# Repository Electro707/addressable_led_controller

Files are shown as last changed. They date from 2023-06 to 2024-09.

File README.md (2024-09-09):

# Addressable LED Strip Controller
#### Rev 4

This is the repository for my LED strip controller. This LED controller is capable of controlling any addressable LED strip (1 or two data wires).

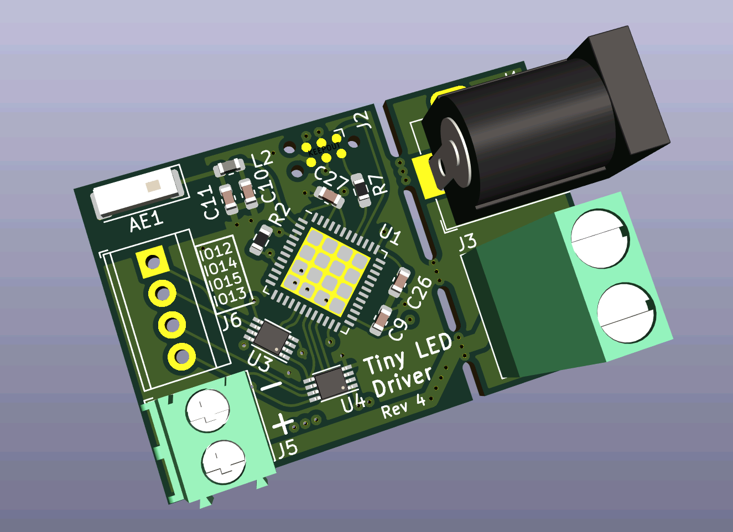
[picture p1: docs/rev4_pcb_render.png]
PCB render of Rev4


`Image of real PCB Rev4 coming soon!`

## Firmware

This controller uses the [WLED firmware](https://github.com/Aircoookie/WLED). Instructions to upload the firmware unto the board can be found on their webpage.

Thru J2, you can connect an ESP32 programmer such as the ESP-Prog. You can also make your own "automatic downloader" (i.e not requiring to reset the device and selecting boot mode when uploading) circuit. Details of which can be found on Espressif's ESP-Prog docs on [Automatic Downloading Function](https://espressif-docs.readthedocs-hosted.com/projects/espressif-esp-iot-solution/en/latest/hw-reference/ESP-Prog_guide.html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).

## PI Matching Network Values

#### Rev 2

The PI Matching network values have been calculated by measuring the impedance of the antenna mounted on a bare board. As image of the setup is shown below:

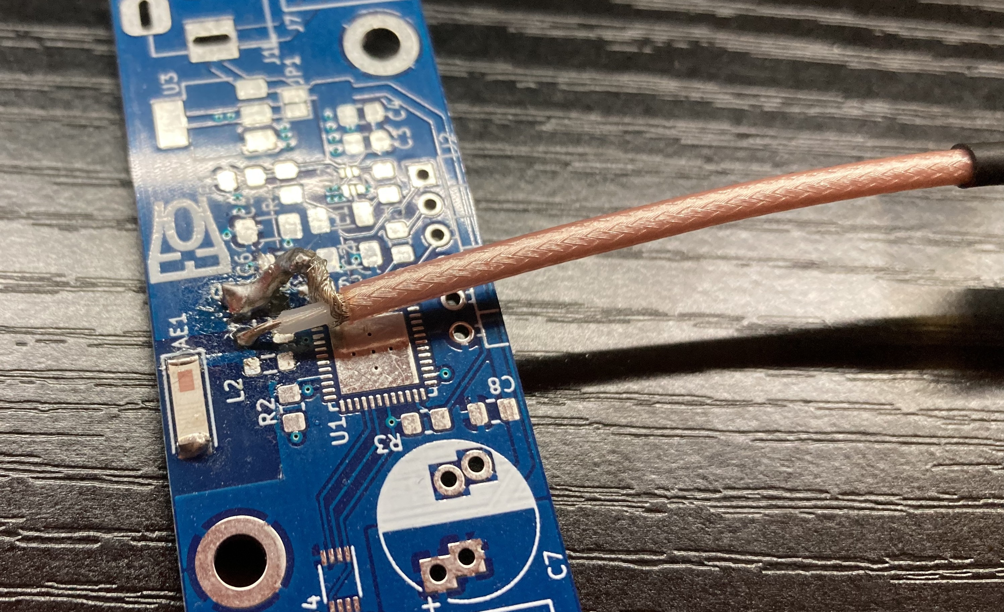
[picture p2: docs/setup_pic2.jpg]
Image of PCB Setup

Image of Setup

The impedance was measured with my handy NanoVNA V2+4. The measured impedance at 2.45Ghz, shown below, was 21.9+5.48jΩ. Plugging those numbers into a [PI matching network calculator](https://www.eeweb.com/tools/pi-match/), we get 2.09nH for L, 2.65pF for Cs, and 3.99pF for Cl. The values have been rounded to the nearest available values that is reasonable to buy (this is RF anyways, I could have sneezed and the values would be slightly off).

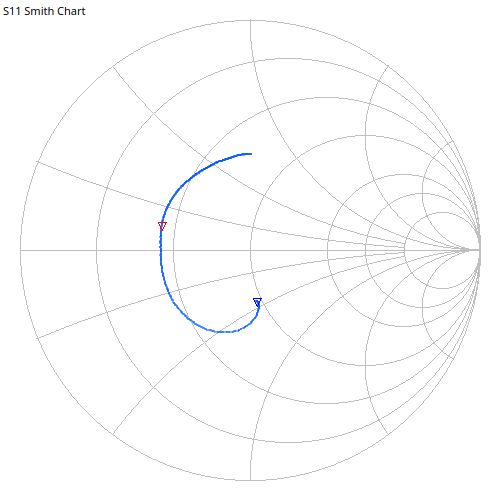
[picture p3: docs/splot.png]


#### Rev 4

At 2.45Gz, impedance was 17.5-35.8jΩ. We get 2.3194nH for L, 3.898pF for Cs, and 4.429pF for Cl.

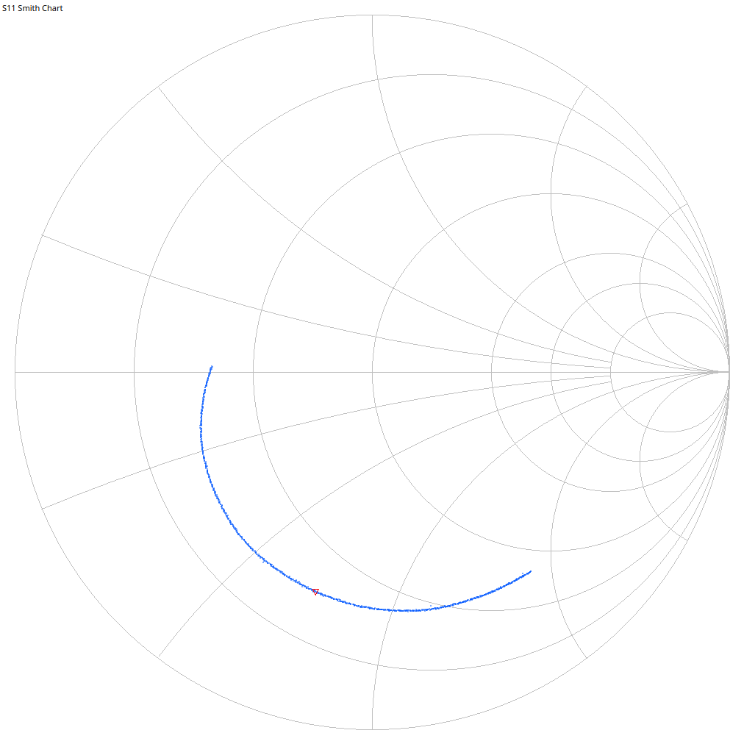
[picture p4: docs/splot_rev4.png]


## Rev 3 Branch-Off

Rev 3 of this project was a fully-featured POE version of this controller. I since has made this revision, which is closer to the original small design, so I decided to branch Rev3 off to it's own repo: [Electro707/addressable_led_controller_poe](https://github.com/Electro707/addressable_led_controller_poe)

## Rev 4 Design Reasonings

Over at [DesignConsiderations.md](DesignConsiderations.md), I wrote some design reasonings as to why some things are the way they are designed for Rev 4 of the board. Feel free to have a look, keep in mind they are more internal notes if anything.

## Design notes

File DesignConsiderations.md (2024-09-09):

# Design Goals
- A tiny single-addressable strip controller
    - 12v or 5v variants, with either a single or dual data lines such as APA102, or WS2815
- Wireless Control
- Be powered from the same power rail as the LED controller

# Design Reasonings
- Using a switching regulator instead of an LDO
    - At 5v, there would be a 0.3-0.5W power drop across the regulator. A bit wasteful, no?
        - also needs a large heatsink
    - With the potential for a 12v, input, the power drop goes up to 1.7-2.6W. Toasty!
- ESP32 for MCU
    - cheap
    - common
    - wifi and ble built-in
    - WLED supports it already
    - need I say more?
- Barrel Jack and wire input
    - for convinience, so small LED runs can be powered with a single barrel jack without wiring that to the LED seperatly.
    - on the PCB, the width already exist due to the antenna and LED connector
- No mounting holes
    - Reduction in size: an M3 screw looks HUGE on the board
- lack of a 1000uF LED supply capacitor
    - size
    - a tht capacitor will consume both top and bottom space

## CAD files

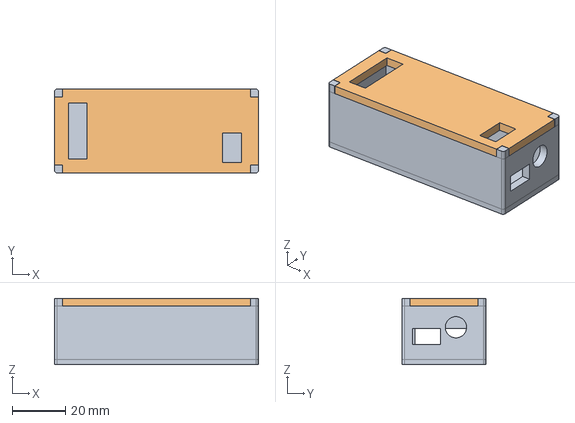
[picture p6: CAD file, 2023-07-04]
CAD/Case1.FCStd
76.7 x 31.6 x 25.0 mm
TopCover

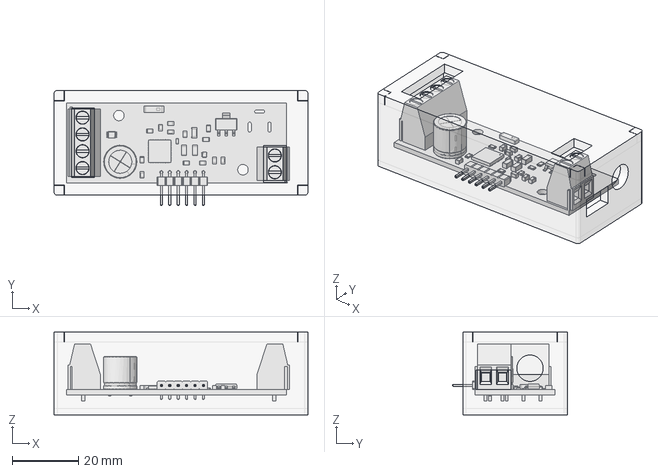
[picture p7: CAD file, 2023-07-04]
CAD/Ass.FCStd
76.7 x 34.7 x 25.0 mm
Case1_001
LED_Controller1_001

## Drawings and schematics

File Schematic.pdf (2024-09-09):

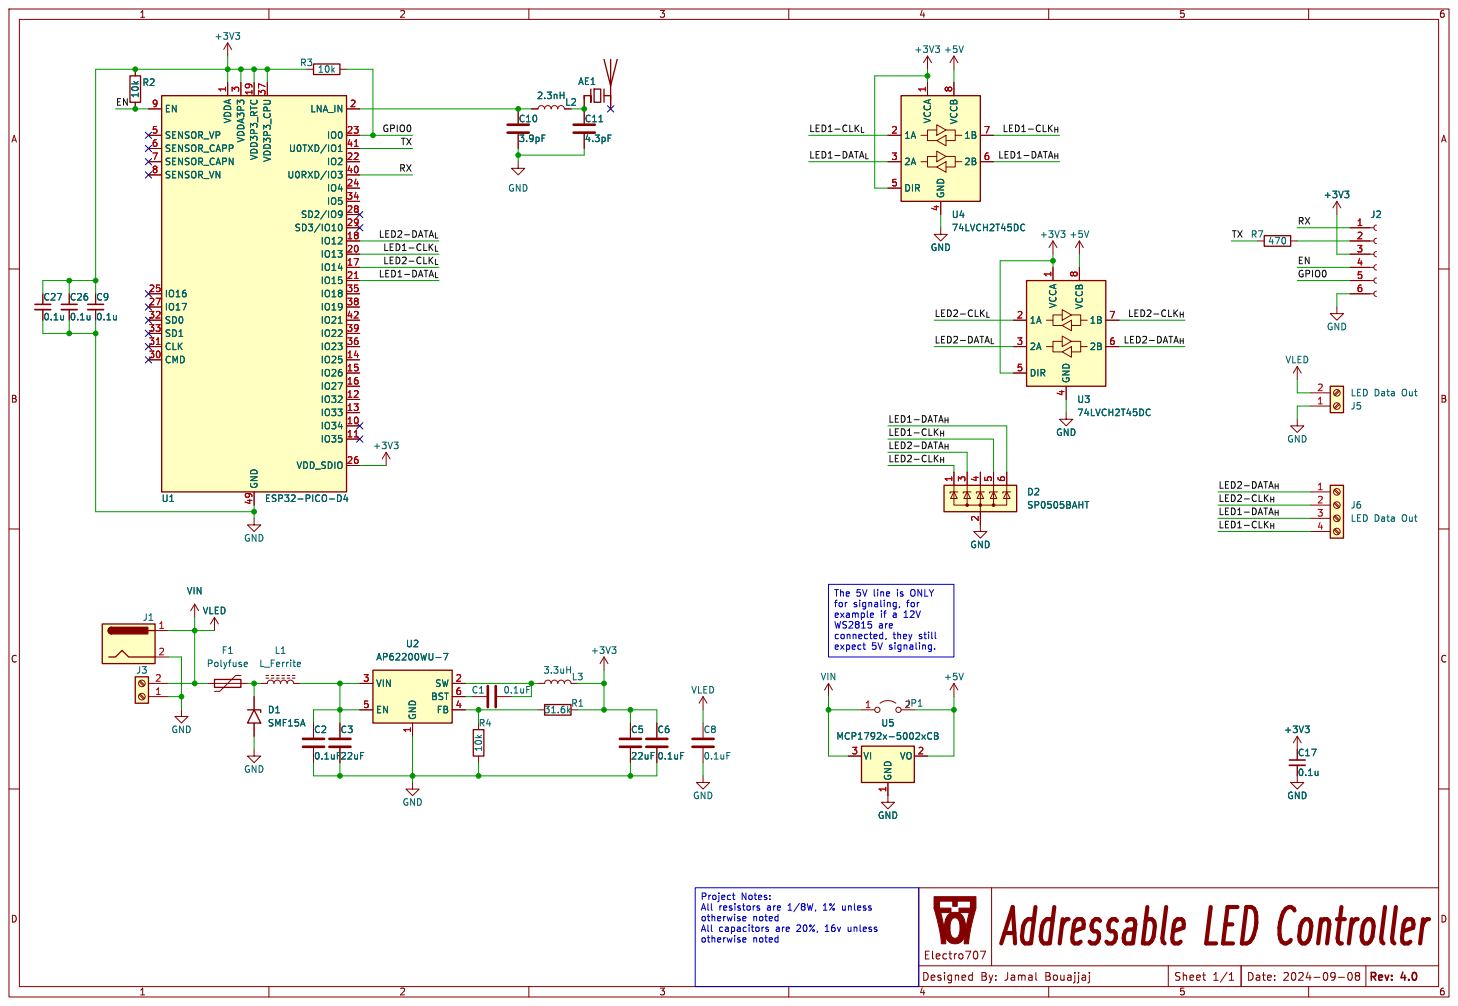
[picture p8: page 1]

LED Data Out GND

1 SW 2 VIN 3 FB 4 EN 5 BST 6 U2 AP62200WU-7 C3

1 SW 2 VIN 3 FB 4 EN 5 BST 6 C2

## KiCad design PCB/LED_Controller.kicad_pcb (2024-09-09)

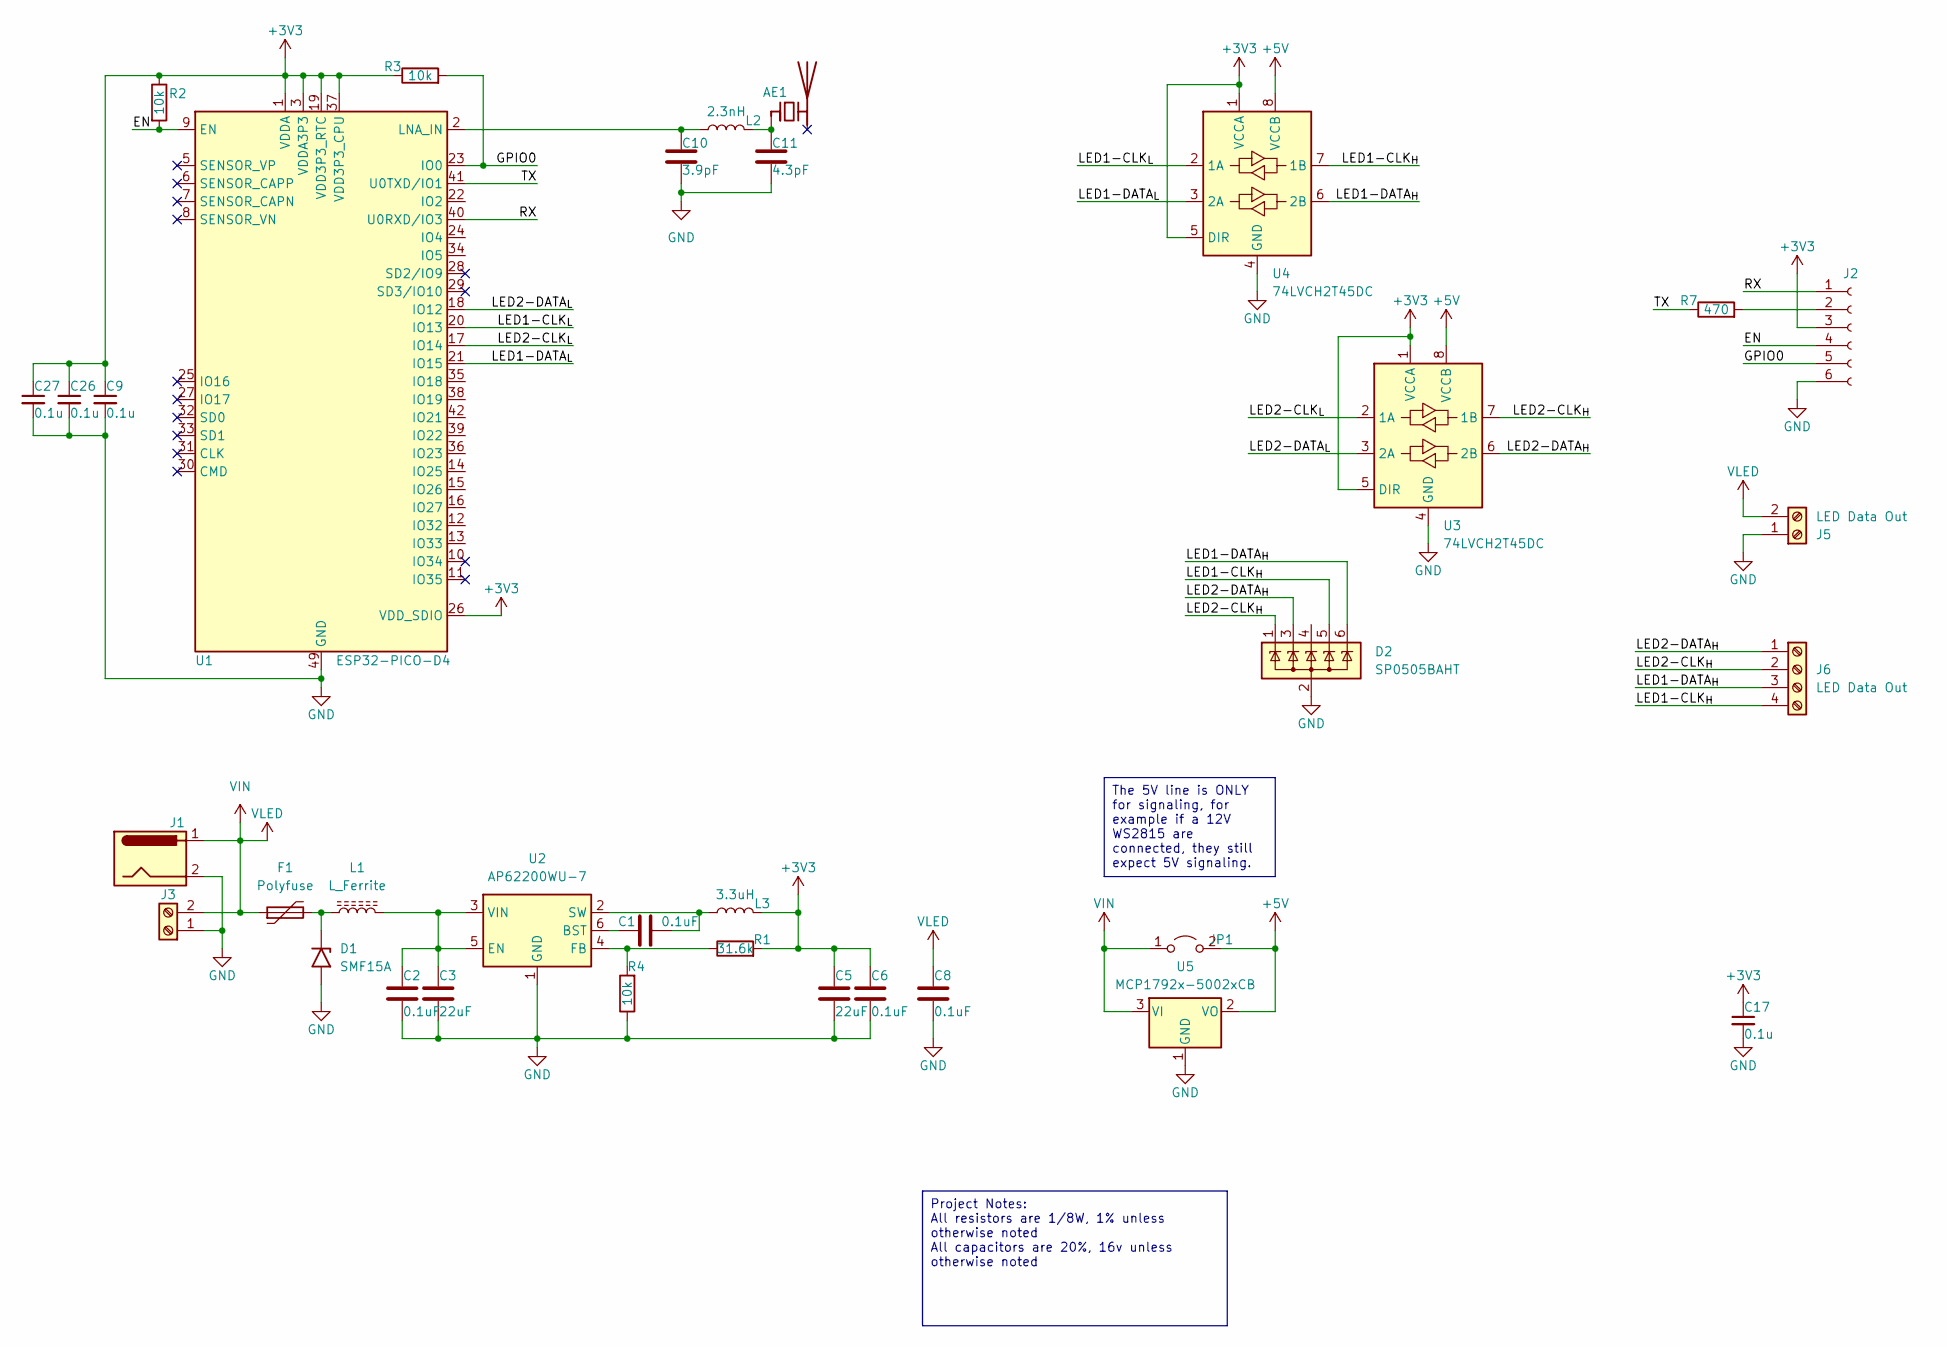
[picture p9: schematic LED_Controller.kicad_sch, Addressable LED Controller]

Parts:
AE1: Antenna_Chip; Johanson_2450AT43F0100
C1, C2, C6, C8: 0.1uF; C_0603_1608Metric
C3, C5: 22uF; C_1206_3216Metric_Pad1.33x1.80mm_HandSolder
C9, C17, C26, C27: 0.1u; C_0603_1608Metric
C10: 3.9pF; C_0603_1608Metric
C11: 4.3pF; C_0603_1608Metric
D1: SMF15A; D_SMF
D2: SP0505BAHT; SOT-23-6
F1: Polyfuse; Fuse_1206_3216Metric
J1: Barrel_Jack; BarrelJack_Horizontal
J2: Conn_01x06_Female; Tag-Connect_TC2030-IDC-NL_2x03_P1.27mm_Vertical
J3: Screw_Terminal_01x02; TerminalBlock_Phoenix_MKDS-1,5-2-5.08_1x02_P5.08mm_Horizont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
J5: LED Data Out; TerminalBlock_Phoenix_PT-1,5-2-3.5-H_1x02_P3.50mm_Horizontal
J6: LED Data Out; TerminalBlock_TE_282834-4_1x04_P2.54mm_Horizontal
JP1: Jumper_2_Bridged; SolderJumper-2_P1.3mm_Open_TrianglePad1.0x1.5mm
L1: L_Ferrite; L_0805_2012Metric
L2: 2.3nH; L_0603_1608Metric
L3: 3.3uH; L_1206_3216Metric_Pad1.22x1.90mm_HandSolder
R1: 31.6k; R_0805_2012Metric_Pad1.20x1.40mm_HandSolder
R2, R3: 10k; R_0603_1608Metric
R4: 10k; R_0805_2012Metric_Pad1.20x1.40mm_HandSolder
R7: 470; R_0603_1608Metric_Pad0.98x0.95mm_HandSolder
U1: ESP32-PICO-D4; QFN-48-1EP_7x7mm_P0.5mm_EP5.3x5.3mm
U2: AP62200WU-7; TSOT-23-6
U3, U4: 74LVCH2T45DC; VSSOP-8_2.3x2mm_P0.5mm
U5: MCP1792x-5002xCB; SOT-23

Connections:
+3V3: C5.1, C6.1, C9.1, C17.1, C26.1, C27.1, J2.3, L3.2, R1.2, R2.1, R3.1, U1.1 (VDDA), U1.3 (VDDA3P3), U1.4 (VDDA3P3), U1.19 (VDD3P3_RTC), U1.26 (VDD_SDIO), U1.37 (VDD3P3_CPU), U1.43 (VDDA), U1.46 (VDDA), U3.1 (VCCA), U3.5 (DIR), U4.1 (VCCA), U4.5 (DIR)
+5V: JP1.2 (B), U3.8 (VCCB), U4.8 (VCCB), U5.2 (VO)
/EN: J2.4, R2.2, U1.9 (EN)
/GPIO0: J2.5, R3.2, U1.23 (IO0)
/LED1-CLK_{H}: D2.5 (K), J6.4, U4.7 (1B)
/LED1-CLK_{L}: U1.20 (IO13), U4.2 (1A)
/LED1-DATA_{H}: D2.6 (K), J6.3, U4.6 (2B)
/LED1-DATA_{L}: U1.21 (IO15), U4.3 (2A)
/LED2-CLK_{H}: D2.1 (K), J6.2, U3.7 (1B)
/LED2-CLK_{L}: U1.17 (IO14), U3.2 (1A)
/LED2-DATA_{H}: D2.3 (K), J6.1, U3.6 (2B)
/LED2-DATA_{L}: U1.18 (IO12), U3.3 (2A)
/RX: J2.1, U1.40 (U0RXD/IO3)
/TX: R7.1, U1.41 (U0TXD/IO1)
GND: C2.2, C3.2, C5.2, C6.2, C8.2, C9.2, C10.2, C11.2, C17.2, C26.2, C27.2, D1.2 (A2), D2.2 (A), J1.2, J2.6, J3.1, J5.1, R4.1, U1.49 (GND), U2.1 (GND), U3.4 (GND), U4.4 (GND), U5.1 (GND)
unnamed: AE1.1 (FEED), C11.1, L2.2
unnamed: D1.1 (A1), F1.2, L1.1
unnamed: J2.2, R7.2
unnamed: C10.1, L2.1, U1.2 (LNA_IN)
unnamed: C1.1, U2.6 (BST)
unnamed: C2.1, C3.1, L1.2, U2.3 (VIN), U2.5 (EN)
unnamed: R1.1, R4.2, U2.4 (FB)
unnamed: C1.2, L3.1, U2.2 (SW)
VIN: C8.1, F1.1, J1.1, J3.2, J5.2, JP1.1 (A), U5.3 (VI)

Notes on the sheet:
Project Notes: All resistors are 1/8W, 1% unless otherwise noted All capacitors are 20%, 16v unless otherwise noted
The 5V line is ONLY for signaling, for example if a 12V WS2815 are connected, they still expect 5V signaling.

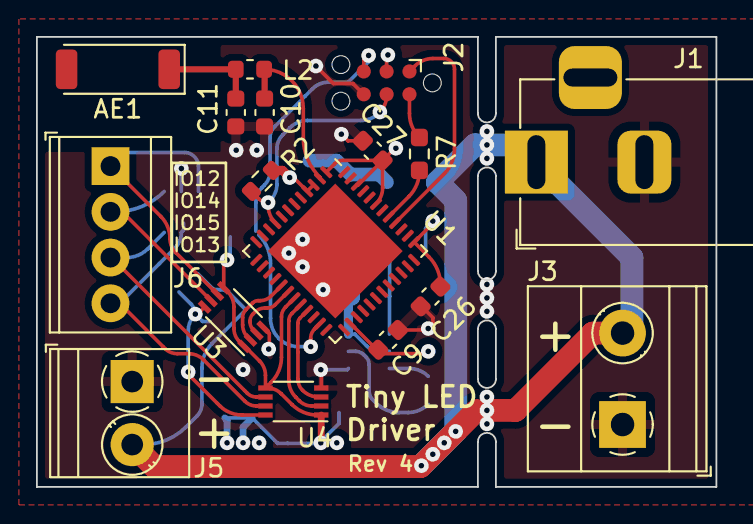
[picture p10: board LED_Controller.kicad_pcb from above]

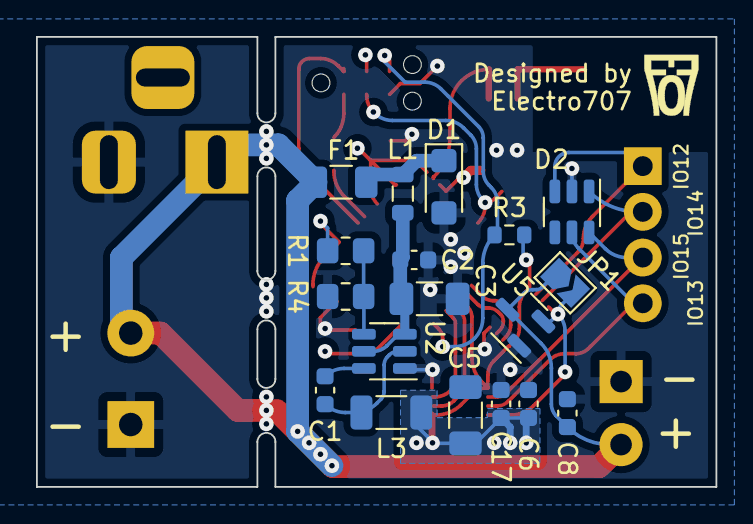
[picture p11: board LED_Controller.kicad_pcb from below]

Board: 4 copper layers, 37.8 x 25.0 mm, 35 parts (18 on the bottom side), 24 nets.

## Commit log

2023-06-24 Rev 1 push
    [LED_Controller.kicad_pcb, LED_Controller.kicad_sch]
2023-06-24 Rev 2.0 local push
    [Ass.FCStd, Case1.FCStd, LED_Controller.kicad_pcb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]
2023-06-25 Updated README to include impedance matching calculation Updated case for screw tollerance Updated schematic to fill in values for PI network
    [Case1.FCStd, LED_Controller.kicad_sch]
2023-07-04 Updated CAD Drawing
    [Ass.FCStd, Case1.FCStd]
2023-07-05 Started work on V3 of PCB
    [LED_Controller.kicad_sch]
2023-07-05 More work, added ethernet controller and ethernet pin
    [LED_Controller.kicad_sch]
2023-07-05 Moved new symbol to internal library
    [LED_Controller.kicad_sch]
2023-07-27 More work, including hierarchical sheets breakout
    [LED_Controller.kicad_sch, ethernet.kicad_sch, poe_power.kicad_sch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]
2023-07-30 Started on board layout
    [LED_Controller.kicad_pcb, LED_Controller.kicad_sch, ethernet.kicad_sch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]
2023-07-31 Started serious board layout
    [LED_Controller.kicad_pcb, LED_Controller.kicad_sch, poe_power.kicad_sch]
2023-08-01 More layout work
    [LED_Controller.kicad_pcb, LED_Controller.kicad_sch]
2023-08-04 Close-to-final PCB layout, passes most routing DRC I think
    [LED_Controller.kicad_pcb]
2023-08-07 Almost-Almost PCB design. Minor improvements on copper layer Silkscreen cleanup schematic sheet cleanup (now with subsheet titles)
    [LED_Controller.kicad_pcb, ethernet.kicad_sch, poe_power.kicad_sch]
2023-08-11 Final Rev 3 board
    Many changes that are finalization changes mostly
    [LED_Controller.kicad_pcb, LED_Controller.kicad_sch, ethernet.kicad_sch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]
2023-10-02 Updated schematic on repo. Added so cap have voltage rating on schematic
    [poe_power.kicad_sch]
2024-09-09 Updated to Rev 4
    [LED_Controller.kicad_pcb, LED_Controller.kicad_sch, ethernet.kicad_sch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]
